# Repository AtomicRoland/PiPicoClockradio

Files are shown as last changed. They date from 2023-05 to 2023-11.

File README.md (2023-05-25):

# PiPicoClockradio
A simple clock radio based on a Pi Pico, TM1637 display module and TDA5807 Stereo FM receiver.

# Installation                              
The first step is to install BBC Basic on the Pico, if you haven't already done 
so. The designers of the Pico have thought carefully about how you can provide 
the Pico with the program (firmware) you want to use as simply as possible. This 
can be a program with a specific task (such as my Electron Video card), but also 
an environment with a programming language such as Micro Python or of course BBC Basic.

There is a small white push button on the Pico to select the boot mode. If you 
turn on the Pico without pressing this button, it will start normally. However, 
if you press this button and then connect the Pico to your computer, it will be
shown as a USB drive in the Finder (Apple MacOS) or Explorer (Windows). All you 
have to do is drag the file with your program or firmware to the drive icon of the
Pi Pico. The file will then be copied to the Pico's flash memory and when finished,
the Pico will automatically reboot and start your program or firmware.

Let's do this step by step:
     • If the Pico is connected to your computer, disconnect it for a while.
     • In the file Explorer or Finder open the folder where 
       bbcbasic_console_rpico.uf2 is located.
     • Press the white button and connect the USB cable to your computer with your 
       other hand.
     • A new “drive” icon will now appear in the Finder or Explorer. This is 
       called RPI-RP2.
     • Drag and drop the uf2 file to this icon.
     • Wait a moment until the file has been copied and the Pico restarts 
       automatically.

During this restart, your computer may prompt you to unmount (eject) the media 
before removing it. Ignore this message, the file has been successfully copied 
and it can do no harm to remove the medium  without to eject it.
BBC Basic is now installed and ready to use.

The second step is to install the clock radio program. Step by step it goes as 
follows:
     • Open the clockradio.txt file in a text editor
     • Select the entire text and copy it to the clipboard
     • In BBC Basic type the command
        	NEW <enter>
     • Paste the text into the console window
     • When the text is pasted, press ESCAPE
     • Save the file with the name autorun.bbc

With these steps, the clock radio is ready to use. You can now start the program 
directly with the RUN statement. By using the name autorun.bbc the program will 
start automatically when the Pico is powered on or reset.

Have fun with it!

# License

The license for this Work (i.e. both the hardware and software) is simple:

1. You have the right to use the Work in any way you want for non-commercial use. Commercial use is considered when you integrate the Work into your own products or replicate the Work and sell it.

2. You may create your own hardware and software based on the Work for non-commercial use. However, for deviated projects you must use the same license.

# Warranties and Disclaimer

Except as required by law, the Work is licensed by the Licensor on an "as is" and "as available" basis and without any warranty of any kind, either express or implied.

# Limit of Liability

Subject to any liability which may not be excluded or limited by law the Licensor shall not be liable and hereby expressly excludes all liability for loss or damage howsoever and whenever caused to You.

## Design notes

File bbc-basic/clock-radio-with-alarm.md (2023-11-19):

Although I use the wake-up function regularly and as far as I know it functions well, I accept no liability whatsoever in the event that you oversleep and therefore arrive late for work/appointment or miss your plane. So use at your own risk ;-)

USAGE
=====

The buttons and LEDs have been given a new function. The buttons, from left to right, have the following meaning:

_1st key: A for Alarm_
This button switches on the alarm. The set alarm time appears on the display for 15 seconds. The red LED turns on, indicating that the alarm is active. When the alarm time is reached, the radio turns on. By pressing the A button you switch off the radio for ten minutes (snooze). Pressing the R button turns the radio off. However, the alarm remains active for the next day. If the alarm is active, you can turn it off by pressing the A button again.

_2nd key: R for Radio_
This button switches the radio on or off. When switched on, the set frequency appears on the display for 15 seconds. If you press and hold the R button for three seconds when switching on, you will switch on the sleep timer function. You can choose from 15, 30, 45 or 60 minutes. Enabling the sleep timer disables the snooze function.

_3rd key: M for Mode_
This is the button to set the settings of the clock radio. When pressed repeatedly, this button shows the function to be set. These are successively:
Temperature: shows the temperature (this cannot be changed). The temperature is measured with the CPU's internal sensor. In fact, the temperature of the processor is displayed and not the ambient temperature. Since this clock does not require much from the processor, the processor temperature will reasonably correspond to the ambient temperature. To prevent excessively variable displays of the temperature, it is measured a maximum of once per minute.
Time: the letter 't' will appear on the display, then press the H- and/or M+ key to set the time.
Alarm: the letter 'A' appears on the display, then press the H- and/or M+ key to set the time.
Loudness: the display will show the letter 'L', then press the H- button to increase the volume or the M+ button to decrease the volume. The volume can be adjusted in a range of 0 – 15.
Brightness: the letter 'b' will appear on the display, then press the H- key to increase the brightness of the display or the M+ key to decrease the brightness. The brightness can be adjusted in a range of 0 – 7. In position 'A' the brightness is automatically set to day and night.
Frequency: the display will show the letter 'F', then press the H- button to search for a radio station on a lower frequency or the M+ button to search for a station on a higher frequency. The frequency range is from 87 – 108 MHz. The last frequency set is saved.
Carousel: the display shows the time, radio frequency and temperature in succession for 20 seconds.
If the radio is not switched on when using the Mode button, the settings for Loudness and Frequency will not be displayed. The frequency will also not be displayed in the carousel.

_4th Key: H-_
This key increases the hours when setting the time or alarm time. With the other settings, this button reduces the set value.

_5th Key: M+_
This button increases the minutes when setting the time or alarm time. For the other settings, this button increases the set value.

If no key is pressed for 15 seconds, the time will be displayed again, unless the carousel function has been selected.

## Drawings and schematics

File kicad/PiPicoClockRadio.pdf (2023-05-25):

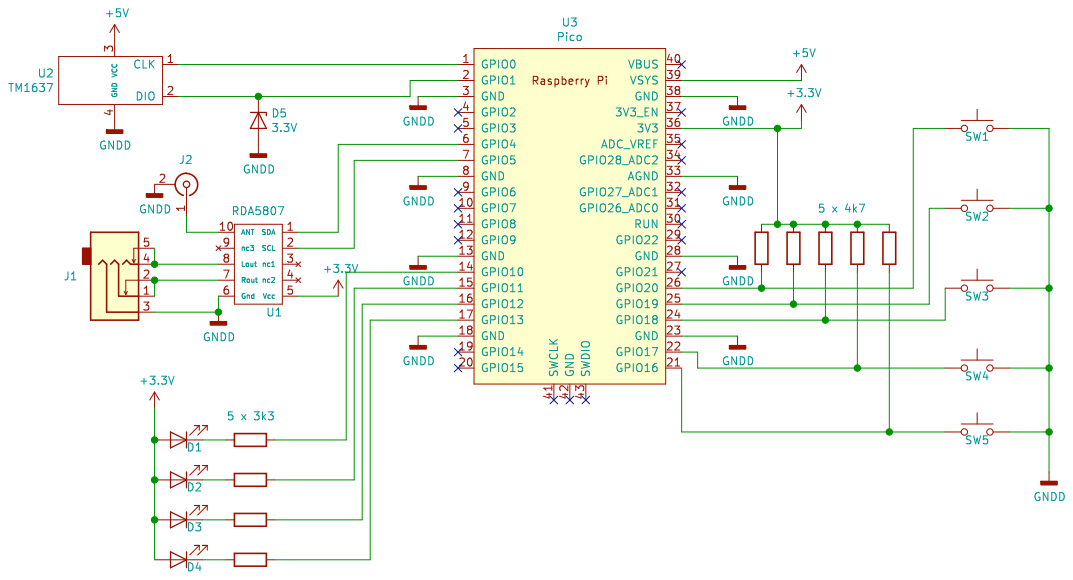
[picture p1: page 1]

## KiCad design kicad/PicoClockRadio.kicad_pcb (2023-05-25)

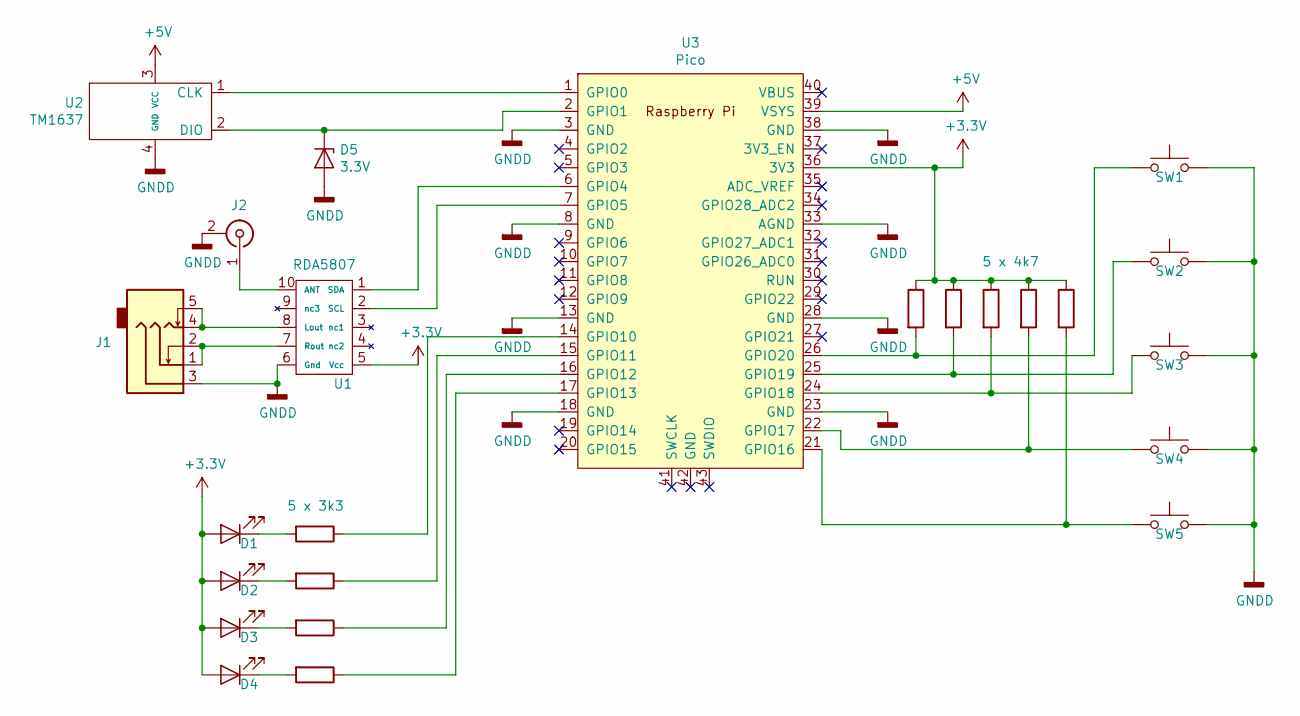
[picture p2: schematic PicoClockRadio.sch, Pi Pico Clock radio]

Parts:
D1, D2, D3, D4: LED; LED_D3.0mm
D5: 3.3V; D_A-405_P7.62mm_Horizontal
J1: AudioJack3_SwitchTR; 3.5mm audio stereo
J2: Conn_Coaxial; RCA connector
R1, R2, R3, R4, R7, R8, R9: R; R_Axial_DIN0207_L6.3mm_D2.5mm_P10.16mm_Horizontal
R5: 5 x 4k7; R_Axial_DIN0207_L6.3mm_D2.5mm_P10.16mm_Horizontal
R6: 5 x 3k3; R_Axial_DIN0207_L6.3mm_D2.5mm_P10.16mm_Horizontal
SW1, SW2, SW3, SW4, SW5: SW_Push; SW_PUSH-12mm
U1: RDA5807
U2: TM1637
U3: Pico; RPi_Pico_SMD_TH

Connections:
+3V3: D1.2 (A), D2.2 (A), D3.2 (A), D4.2 (A), R1.1, R2.1, R3.1, R4.1, R5.1, U1.5 (Vcc), U3.36 (3V3)
+5V: U2.3 (VCC), U3.39 (VSYS)
GNDD: D5.2 (A), J1.3, J2.2 (Ext), SW1.2, SW2.2, SW3.2, SW4.2, SW5.2, U1.6 (Gnd), U2.4 (GND), U3.3 (GND), U3.8 (GND), U3.13 (GND), U3.18 (GND), U3.23 (GND), U3.28 (GND), U3.33 (AGND), U3.38 (GND)
unnamed: D1.1 (K), R6.2
unnamed: D2.1 (K), R7.2
unnamed: D3.1 (K), R8.2
unnamed: D4.1 (K), R9.2
unnamed: D5.1 (K), U2.2 (DIO), U3.2 (GPIO1)
unnamed: J1.1, J1.2, U1.7 (Rout)
unnamed: J1.4, J1.5, U1.8 (Lout)
unnamed: J2.1 (In), U1.10 (ANT)
unnamed: R1.2, SW1.1, U3.26 (GPIO20)
unnamed: R2.2, SW2.1, U3.25 (GPIO19)
unnamed: R3.2, SW3.1, U3.24 (GPIO18)
unnamed: R4.2, SW4.1, U3.22 (GPIO17)
unnamed: R5.2, SW5.1, U3.21 (GPIO16)
unnamed: R6.1, U3.14 (GPIO10)
unnamed: R7.1, U3.15 (GPIO11)
unnamed: R8.1, U3.16 (GPIO12)
unnamed: R9.1, U3.17 (GPIO13)
unnamed: U1.1 (SDA), U3.6 (GPIO4)
unnamed: U1.2 (SCL), U3.7 (GPIO5)
unnamed: U2.1 (CLK), U3.1 (GPIO0)

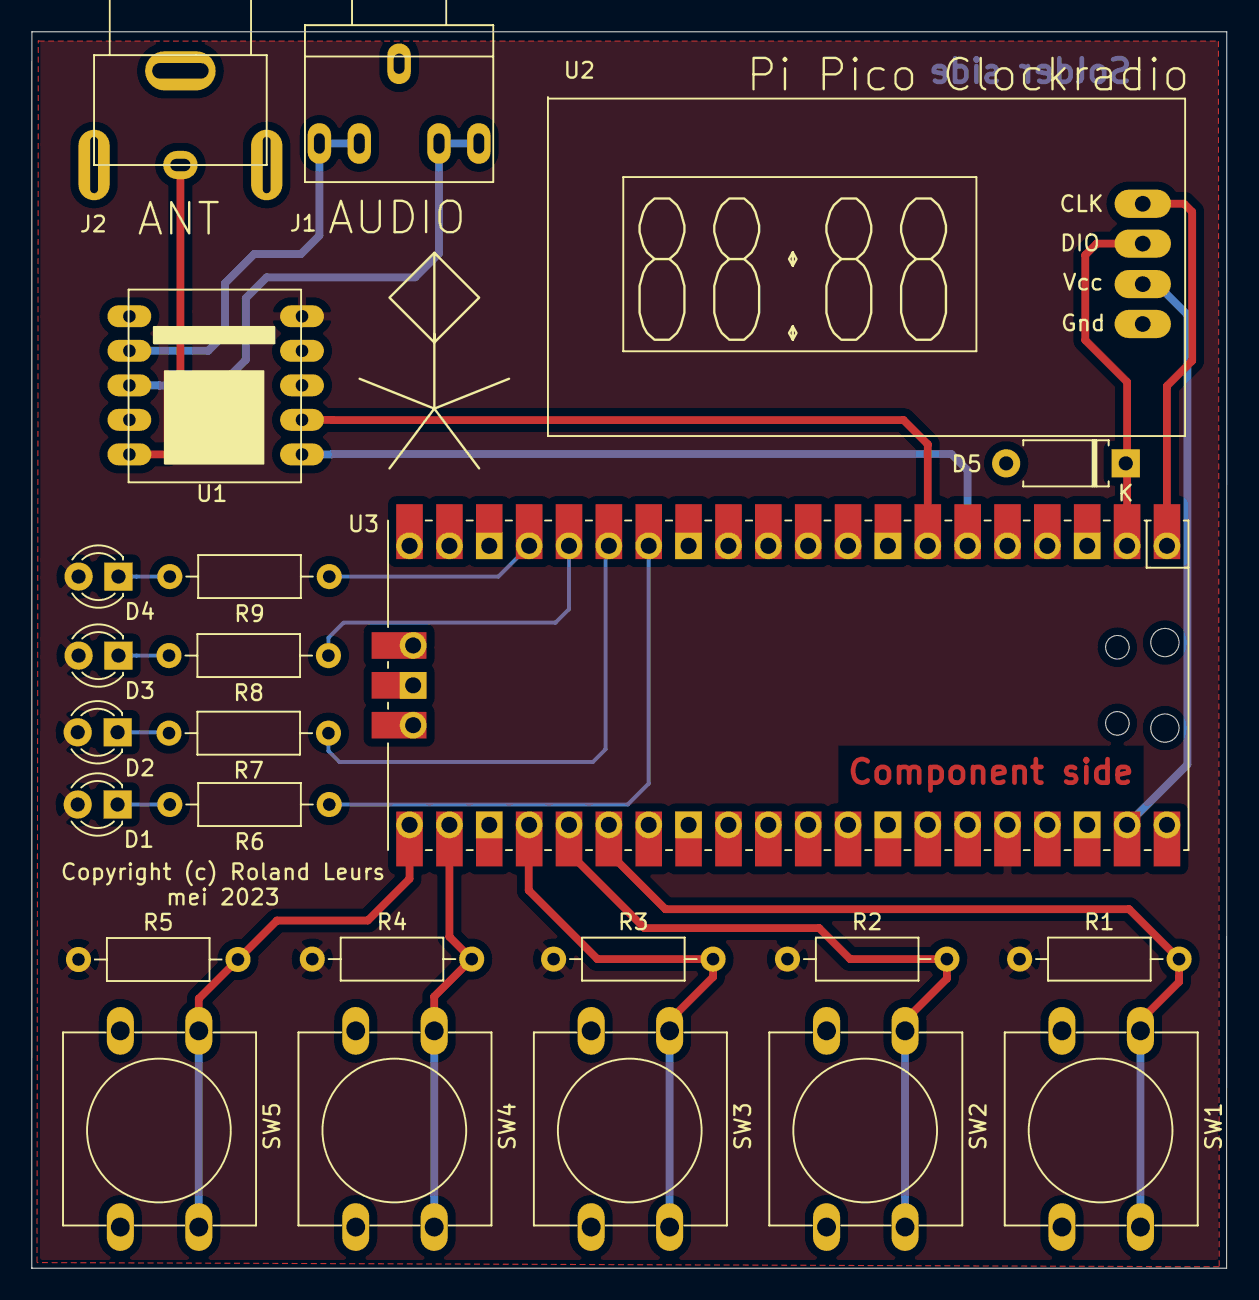
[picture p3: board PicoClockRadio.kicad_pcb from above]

Board: 2 copper layers, 76.1 x 78.8 mm, 24 parts (0 on the bottom side), 23 nets.

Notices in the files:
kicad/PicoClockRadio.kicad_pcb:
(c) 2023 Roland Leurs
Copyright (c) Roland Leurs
